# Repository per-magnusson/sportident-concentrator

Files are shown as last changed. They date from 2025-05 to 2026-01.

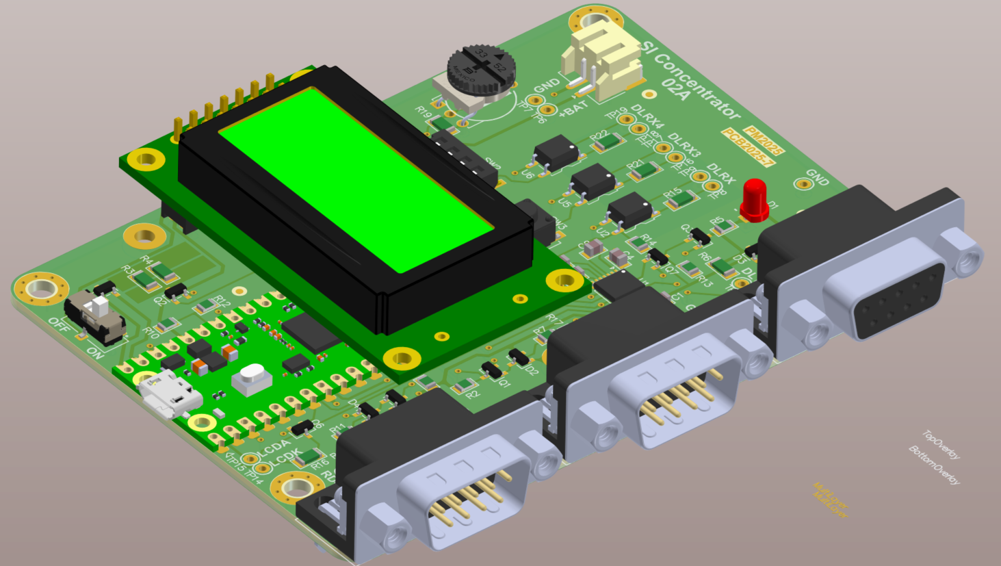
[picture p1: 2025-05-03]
hardware/SI concentrator 3D.png

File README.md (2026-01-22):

# Sportident Concentrator Box

This project consists of both the hardware and the software for a Sporitdent  
concentrator box based on a Raspberry Pi Pico.

photo of the concentrator

It is useful in the sport of orienteering where the Sporitdent punching system is used and allows
punch data from the terrain to be brought in real time to the speaker at the event and to online results. The box
can receive punch data from up to four BSF7 RS232 statations (or other concentrator boxes), plus from a 
long wire from another concentrator box. It buffers the punch data and sends it out over:

- A long wire (1 km or even more is supported)  
- A USB port to a computer  
- An RS232 serial port  

It can be powered by a USB power bank, from a computer via the USB cable or from a pack of e.g. three AA
batteries or another source that provides between 1.8 and 5.5 V.

The box supports both the old Sportident legacy protocal and the current 
extended protocol. It adapts to the speed on the serial port which can be either
4800 or 38400 baud.

It is possible to build a version (useful e.g. at the event center) on the same PCB which has up to three opto-isolated 
long-wire inputs (and correcpondingly fewer RS232 inputs) to receive data from three different long wires.

Since the box in its normal configuration has a long-wire input, it is possible to daisy-chain a number of
concentrator boxes from e.g. the pre-warning via the last control.

To significantly simplify verification of the setup and troubleshooting in the field, there is a 2x8 character 
display that constinuously shows the status of the various inputs. Right after a packet of punch data is 
received, the display shows the card number and station code. 

The USB port shows up as a serial adapter and the punch data can be received by MeOS, OLA and
other orienteering administration software.

The design is based on a Raspeberry Pi Pico (both the original and Pi Pico 2 works) and the code
can be compiled in the Arduino environment.

The project contains the source code, files for manufacturing and assembling the PCB and
files for 3D-printing the enclosure.

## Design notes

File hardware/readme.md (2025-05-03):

# Layout

The board looks something like this:

PCB Rendering

The board has two layers, where most of the routing and the components are on the top side. The 
bottom side is mostly ground plane. Here are the layers:

Top layout
Bottom layout

Here is the assembly drawing:

Assembly drawing

Vectorized versions are avaialble as PDFs in the repo.

Gerber and assembly files are available in the zip files in the repo. The PCB file is the gerbers for the PCB. 
The PCA file contains what is needed for assembly.

The bill of materials (BOM) should be self-explanatory.

# Schematic overview

The schematic is available as a single-page PDF in the repo.

Assembly drawing

## Notation

Components marked "NM" are normally Not Mounted,

## Processor

At the core of the deisgn is a Raspberry Pi Pico 2 board (Pi Pico also works if the code is compiled for that). It 
contains the processor, a USB port and a buck/boost voltage converter. Using this inexpensive board simplifies the rest
of the design so that it should be rather easy to hand-solder for most people with at least a little soldering
experience.

## Power

Power normally comes via the USB cable, either from a power bank or from a computer. There are also provisions to power 
the board from a battery pack (via P5) with a voltage between 1.8 and 5.5 V. E.g. using three AA batteries. The power 
switch SW1 only has an effect if using the battery pack option. Power via the USB port always turns the board on.

Q4 disconnects the battery if power is available from the USB port.

## Serial ports

There are three DB9 connectors directly on the board: two male inputs to be connected to Sportident BSF7 RS232 statations and
one female output to be connected to a serial port on a computer or to another concentrator box. Two more input ports
can easily be added to TP10/TP11 and TP12/TP13, but the DSUB connectors need to be connected to these points by wire.
Alternatively, one or both of these inputs can be configured for long-wire reception by mounting U5/R21 and/or U6/R22 
instead of Q1 and/or Q5.

Only one "proper" RS232 line driver/receiver is used (U1) as there is only one RS232 output. The inputs can be handled
in a simpler and cheaper way by discrete solutions using a MOSFET and a handful of resistors (and ESD protection diodes).

The optocoupler U2 (connected to TP8/TP9) allows for an additional long-wire input from another concentrator box. 

There is also a long-wire output, built around Q7/Q3. It transmits the same data as that transmitted on the serial port
outputs. It is best to use 4800 baud on the long wires as that ensures that reflections are not a problem. Maybe 38400
might work, but that has not been tested and the data volumes in any reasonable scenario are so low that 4800 will do 
just fine. An LED, D1, flashes along with the data sent on the long wire output, which might be helpful during debugging,
particularly if the LCD is not fitted. With the LCD in the design, the LED could be left out without any real loss in 
debuggability.

At least 1 km of DL 1000 cable can be used as the long wire.

If the USB cable is connected to a computer, it shows up as a serial port and the punch data can be received 
by most orienteering administrative software, like OLA and MeOS without any need for a separate RS232-to-USB adapter.

## LCD

The 2x8 character LCD U4 allows for monitoring the status of the box and the communication. This greatly simplifies 
troubleshooting and verification of the setup in the field. However, if it is very important to keep the cost down,
the LCD can be left out without having to modify the software.

The LCD contrast can be adjusted by R18, or if the ideal value is known, the fixed R19 can be mounted instead.

The backlight of the LCD can be controlled by Q6.

The LCD can be mounted on 3D-printed spacers and connects to the main board via a 2x7 pin header.

## Power bank keep-alive

A common way of powering the concentrator box is from a USB power bank via the USB cable. The power consumption 
is however so low that most power banks think that no load is connected, so the power bank switches off its 
output after 30 seconds or so. To prevent this, Q2/R3/R4 can be used to periodically pull more current from
the source to prevent the power bank from going to sleep.

## Config switches

There are provisions for mounting a four-pole DIP switch (SW2) and a push button (SW3). These could be used for 
configuring the device in various ways, but the current software does not read these switches. Accessing
them would requre disassembling the box, which is a bit inconvenient in the field as it requires unscrewing four 
screws. It is probably best to leave these switches unpopulated.
best to not fit them. Configuration could of course also be done by changing and recompiling the code.

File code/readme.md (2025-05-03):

## Compiling

This code is meant to be compiled in the Arduino environment with the addition of the 
Raspberry Pi Pico RP2040/RP2350 board package by Earle F. Philhower, III.
It works on both the Pi Pico and Pi Pico 2 boards.

## The Sportident autosend protocol

The code in SerialInput.cpp handles both the legacy and extended Sportident protocols 
for autosend data. Other kinds of Sportident packages are forwarded as well, but that 
is not thought to be a valid use case, nor is it tested much.

Each packet contains a 16-bit CRC. This is not checked. Packets are passed on regardless 
if the CRC is valid or not.

## Serial ports

PIO/Software serial ports are used throughout. Documentation for the serial port library 
can be found at [Readthedocs](https://arduino-pico.readthedocs.io/en/latest/piouart.html)

Input is taken from up to five serial ports. A standard way of building the box is to have 
four DB9M inputs and one (opto-isolated) long-wire input, but one can e.g. build it with just 
three long-wire inputs. In the latter case, it is suggested that the line:

    #define RECEIVE_ONLY 0

In SI-concentrator.ino is changed to:

    #define RECEIVE_ONLY 1

This changes the printouts on the LCD to only show status of the three ports and defaults them 
all to 4800 baud, which is the speed used on the long wire.

Initially, if an invalid packet is received, the serial speed is toggled between 
4800 baud and 38400 baud. Once a valid packet has been received, the speed is locked 
for that input. Except for the long wire input, the starting speed is 38400.

The output is sent to three places:

1. The female DB9 connector
2. The long-wire output (supports at least 1 km of DL-1000 wire)
3. The USB serial port

## Link status

The (optional) 2x8 LCD displays the status of the different inputs as well as the battery
voltage. There is one character position for each of the five inputs. The possible status 
characters and their meanings are:

'?' - Nothing has been received  
'f' - An invalid packet was received  
't' - There was a timeout while recieving a packet  
'u' - A valid packet of an unexpected type was received  
'tick' - A perfectly valid extended protocol autosend packet was recevied  
'L/E' - A perfectly valid legacy protocol autosend packet was recevied

The status display toggles between the above characeters and another character showing the
link speed for each input:

'3' - 38400 baud  
'4' - 4800 baud

As soon as a valid packet has been received, the backlight is turned on and the card number
as well as the station code is shown for a few seconds. This greatly helps in verifying the
operation of the setup.

## Powerbank keep-alive

A common way of powering the concentrator box is from a USB power bank via the USB cable.
The power consumption is however so low that most power banks think that no load is 
connected, so the power bank switches off its output after 30 seconds or so. To prevent
this, there is a software-controlled feature to periodically (every 25 seconds) draw 
extra current for 1.1 seconds. This prevents the power bank from going to sleep and 
powering down the concentrator box.

It might be necessary to tweak the timing of the current pulses to fit with some specific 
USB power bank. This is done by the following lines in the .ino file:

    static const uint32_t POWER_BANK_PULSE_MS = 1100;         // Length of power bank keep-alive pulse
    static const uint32_t POWER_BANK_PULSE_PERIOD_MS = 25000; // Time between power bank keep-alive pulses

## Debugging

To enable debug printouts, a line in the file debug.h should be changed from:

    #define DEBUG 0
  
to

    #define DEBUG 1
  
This sends debug printouts to the USB serial port. This obviously breaks the Sporitdent 
protocol on that port.

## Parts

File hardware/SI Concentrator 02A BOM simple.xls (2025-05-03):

Product: |  | SI Concentrator
BOM date: |  | 2025-05-03 16:38
Author: |  | PM
# of parts in BOM: |  | 47
# of different parts: |  | 17
Designators | Qty | Description | Package | Manufacturer | Manufacturer PN | Supplier | Supplier PN | Supplier 2 | Supplier 2 PN
R5 | 1 | Resistor, 330 ohm, 0805, 1%, 0.125W | 0805 |  |  | Digikey | 311-330CRCT-ND
R2, R7, R9, R11, R13, R14, R17, R20 | 8 | Resistor, 3.3 kohm, 0805, 1%, 0.125W | 0805
R8, R10, R12 | 3 | Resistor, 47 kohm, 0805, 1%, 0.125W | 0805
R1, R3, R4, R6, R15, R16, R21, R22 | 8 | Resistor, 100 ohm, 1206, 1%, 0.25W | 1206
R18 | 1 | Thumb trimmer, 1 k, 20%, 0.5W, cermet, 250 degrees | PTH | Bourns | 3352E-1-102LF | Digikey | 3352E-102LF-ND | Mouser | 652-3352E-1-102LF
C1, C2, C3, C4, C5 | 5 | Capacitor, 1 uF, 10%, 0805, X7R, 16V | 0805 |  |  | Farnell | 9227792 | Digikey | 1276-6471-1-ND
D2, D3, D4 | 3 | BAV99, dual diode, common anode/cathode, 0.1A, 75V | SOT23 | Taiwan Semiconductor | BAV99,215 | Elfa | 70-181-61 | Digikey | 1727-2914-1-ND
Q1, Q2, Q3, Q5, Q6, Q7 | 6 | BSS138K, NMOS, 50V, 0.2A, 2 ohms, Vth=0.6-1.2V | SOT23 | Fairchild | BSS138K | Digikey | BSS138KCT-ND
 | 0 | DMG2305, PMOS, 0.9V Vth, 20V, 4.2A, 52 mohm | SOT23 | Diodes Inc | DMG2305UX-13 | Digikey | DMG2305UX-13DICT-ND | Mouser | 621-DMG2305UXQ-7
D1 | 1 | 3mm red LED, 35 mcd, 20 mA, 60 degrees, 2.2 V | 3mm | Würth | 151031SS06000 | Mouser | 710-151031SS06000
U1 | 1 | MAX3232, dual RS232 transceiver, 3-5.5 V, 250 kbit/s | TSSOP16 | Texas Instruments | MAX3232EIPWR | Digikey | 296-19436-1-ND | Mouser | 595-MAX3232EIPWR
U3 | 1 | Raspberry Pi Pico 2, SMD version | SMDDIP40 | Raspberry Pi | SC1631 | Mouser | 358-SC1631 | Digikey | 2648-SC1631CT-ND
U2, U5, U6 | 3 | TLP182, optocoupler, AC/DC | 4-SOP | Toshiba | TLP182(GB-TPL,E | Digikey | TLP182(GB-TPLECT-ND | Mouser | 757-TLP182(GB-TPLE
U4 | 1 | 8x2 alphanumeric transreflective LCD | PTH | Raystar Optronics | RC0802A-TIY-ESV | TME | RC0802A-TIY-ESV
 | 0 | JST PH 2-pin header, right angle | SMD | JST sales | S2B-PH-SM4-TB | Digikey | 455-S2B-PH-SM4-TBCT-ND | Electrokit | 41015809
U1A | 1 | Pin header, 2x7, 2.54 mm spacing | PTH | Adam Tech | PH2-14-UA | Digikey | 2057-PH2-14-UA-ND | Mouser | 737-PH2-14-UA
U1B | 1 | Socket header, 2x7, 2.54 mm spacing | PTH | Würth | 61301421821 | Digikey | 732-61301421821-ND | Mouser | 710-61301421821
J1 | 1 | DSUB9, female, right angle | PTH | Assmann | A-DF 09 A/KG-T2S | Digikey | AE10921-ND
P1, P2 | 2 | DSUB9, male, right angle | PTH | Assmann | A-DS 09 A/KG-T2S | Digikey | AE10968-ND
 | 0 | SPDT slide switch | SMD | Nidec | CL-SB-12B-01T | Digikey | 563-1318-1-ND
 | 0 | Tactile switch, 6x6 mm | SMD | C&K | PTS645SL43SMTR92 LFS | Digikey | CKN10880CT-ND | Mouser | 611-PTS645SL43SMTR92
 | 0 | DIP-switch, 4PST | SMD | Same Sky | DS04-254-2-04BK-SMT | Digikey | 2223-DS04-254-2-04BK-SMT-ND

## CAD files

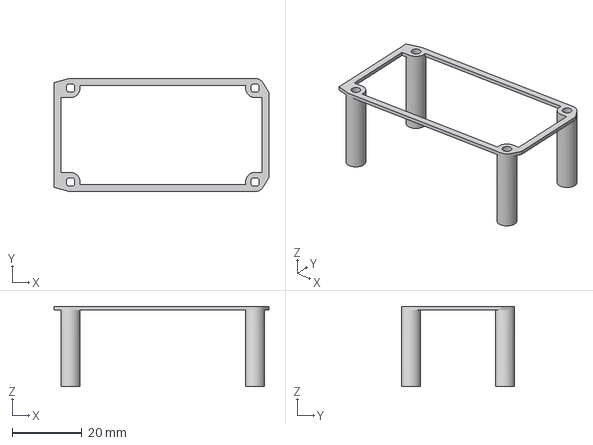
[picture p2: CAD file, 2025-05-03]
3D-printing/LCD standoff.3mf
61.8 x 32.5 x 23.0 mm

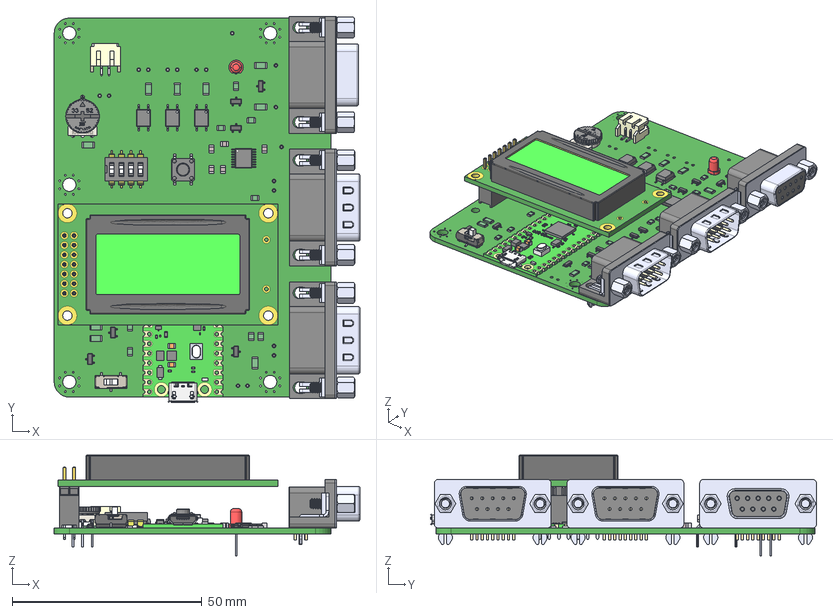
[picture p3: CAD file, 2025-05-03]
hardware/SI Concentrator.step
80.7 x 101.8 x 26.6 mm
TLP182_GB-TPL_E x 3
Extruded x 114
3352E2
sot23-1 x 10
TACT SMD 6X6
Same_Sky_DS04-254-2-04BK-SMT
TSSOP16
_12B-01_c
_2Top setting_s
S2B-PH-SM4-TB
A-DS 09 A_KG-T2S_A-DF 09 A_KG-T2S x 2
A-DF 09 A_KG-T2S_A-DF 09 A_KG-T2S
everlight-3MM-LED-RED
6130xx21821_PIN x 14
lcd
CONN_PH2-14-UA_ADM
ME7SI Concentrator
ME6SI Concentrator
ME5SI Concentrator
PCB, Raspberry Pi Pico-R3
MicroUSB Port, Raspberry Pi Pico-R3
RP2040 Microcontroller, Raspberry Pi Pico-R3
SW1, Tact Switch, Raspberry Pi Pico-R3
D1, Diode, Schottky, Raspberry Pi Pico-R3
D2, QSME-C194, LED, Raspberry Pi Pico-R3
L1, Inductor, Raspberry Pi Pico-R3
U2, RT6150B-33GQW, Buck Boost Converter, Raspberry Pi Pico-R3
U3, W25Q16JVUXIQ, Serial NOR Flash 16 Mbit, Raspberry Pi Pico-R3
Q1, MOSFET, DMG1012T, Raspberry Pi Pico-R3
X1, X12M000000S096, 12 Mhz Crystal Resonator, Raspberry Pi Pico-R3
SMD Resistor, Configurable, Raspberry Pi Pico-R3_R1
SMD Resistor, Configurable, Raspberry Pi Pico-R3_R2
SMD Resistor, Configurable, Raspberry Pi Pico-R3_R3
SMD Resistor, Configurable, Raspberry Pi Pico-R3_R4
SMD Resistor, Configurable, Raspberry Pi Pico-R3_R5
SMD Resistor, Configurable, Raspberry Pi Pico-R3_R6
SMD Resistor, Configurable, Raspberry Pi Pico-R3_R7
SMD Resistor, Configurable, Raspberry Pi Pico-R3_R8
SMD Resistor, Configurable, Raspberry Pi Pico-R3_R9
SMD Resistor, Configurable, Raspberry Pi Pico-R3_R10
SMD Resistor, Configurable, Raspberry Pi Pico-R3_R11
SMD Resistor, Configurable, Raspberry Pi Pico-R3_R12
SMD Resistor, Configurable, Raspberry Pi Pico-R3_R13
SMD Resistor, Configurable, Raspberry Pi Pico-R3_R14
SMD Resistor, Configurable, Raspberry Pi Pico-R3_R15
SMD Capacitor, Configurable, Raspberry Pi Pico-R3_C1
SMD Capacitor, Configurable, Raspberry Pi Pico-R3_C2
SMD Capacitor, Configurable, Raspberry Pi Pico-R3_C3
SMD Capacitor, Configurable, Raspberry Pi Pico-R3_C4
SMD Capacitor, Configurable, Raspberry Pi Pico-R3_C5
SMD Capacitor, Configurable, Raspberry Pi Pico-R3_C6
SMD Capacitor, Configurable, Raspberry Pi Pico-R3_C7
SMD Capacitor, Configurable, Raspberry Pi Pico-R3_C8
SMD Capacitor, Configurable, Raspberry Pi Pico-R3_C9
SMD Capacitor, Configurable, Raspberry Pi Pico-R3_C10
SMD Capacitor, Configurable, Raspberry Pi Pico-R3_C11
SMD Capacitor, Configurable, Raspberry Pi Pico-R3_C12
SMD Capacitor, Configurable, Raspberry Pi Pico-R3_C13
SMD Capacitor, Configurable, Raspberry Pi Pico-R3_C14
SMD Capacitor, Configurable, Raspberry Pi Pico-R3_C15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

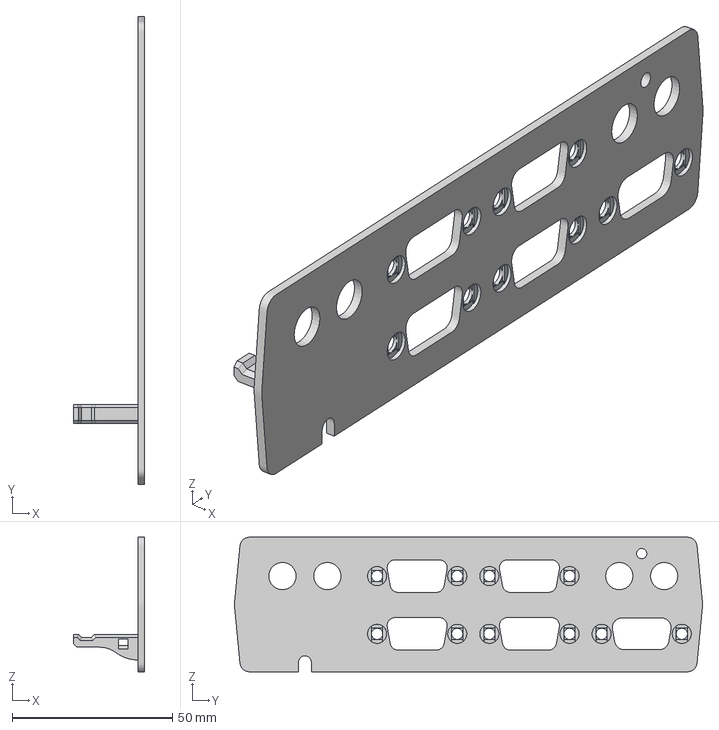
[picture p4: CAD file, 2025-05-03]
3D-printing/SI conc front panel 2.3mf
22.0 x 145.9 x 42.0 mm

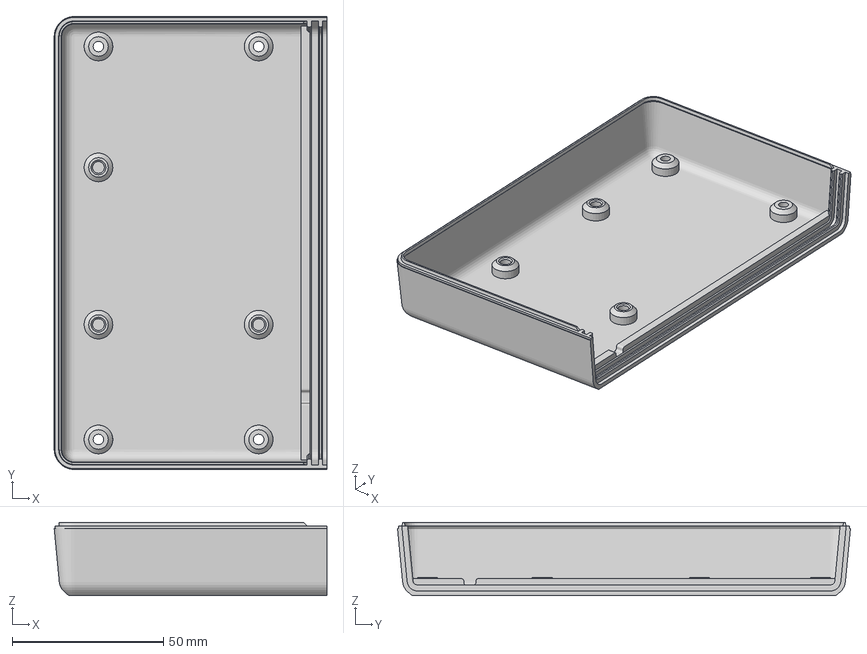
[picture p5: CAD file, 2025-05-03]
3D-printing/SI conc box bottom 2.3mf
90.2 x 149.9 x 24.2 mm

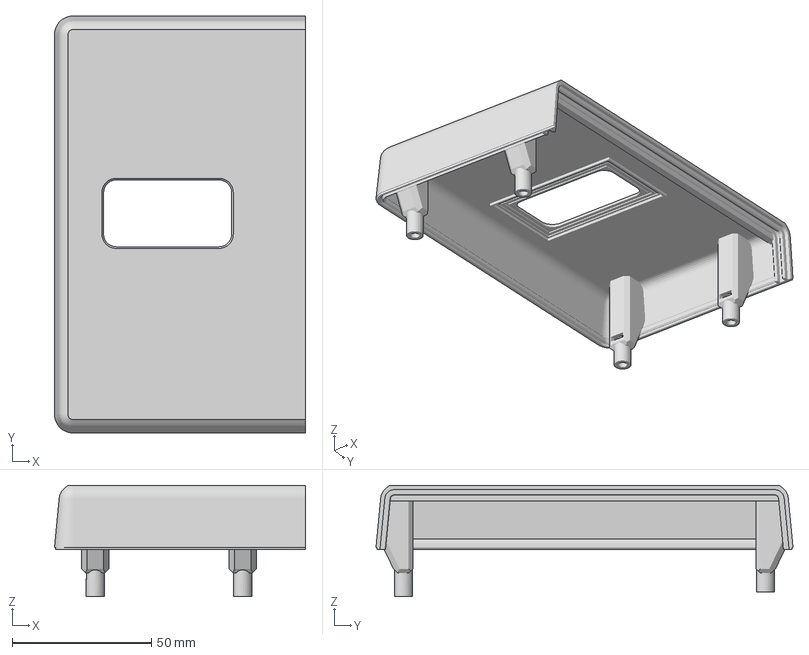
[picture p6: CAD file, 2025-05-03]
3D-printing/SI conc box top 2.3mf
90.2 x 149.9 x 40.0 mm

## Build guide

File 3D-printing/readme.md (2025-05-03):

# Files for 3D printing

The box

The box consists of a bottom, a top and front panel. There is also a four-pillar standoff for the LCD.
All fit on the bed of e.g. a Prusa Mk 3/4 and print without supports.

The box

In addition to the 3D-printed parts, the following additional items are needed:

- A window, 53x31 mm, 1-2 mm thick made of some clear plastic  
- Epoxy glue for the window  
- Three M3 threaded inserts, e.g. IUB-M3-1  
- Three M3 x 6 screws for holding the PCB  
- Four square M3 nuts, e.g. Bossard 1092480  
- Four M3 x 20 screws for holding the box together  
- Eight M2.5 x 6 screws for attaching the LCD  
- A micro USB cable  
- Two small cable ties for strain relief of the USB cable  
- Ten DSUB screwlocks, e.g. Amphenol 863001TLF  
- Four panel-mount banana jacks  
- Wires for connecting the connectors to the board

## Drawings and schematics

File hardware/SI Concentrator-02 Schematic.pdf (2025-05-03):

# SI Concentrator

Date | Revision | Description

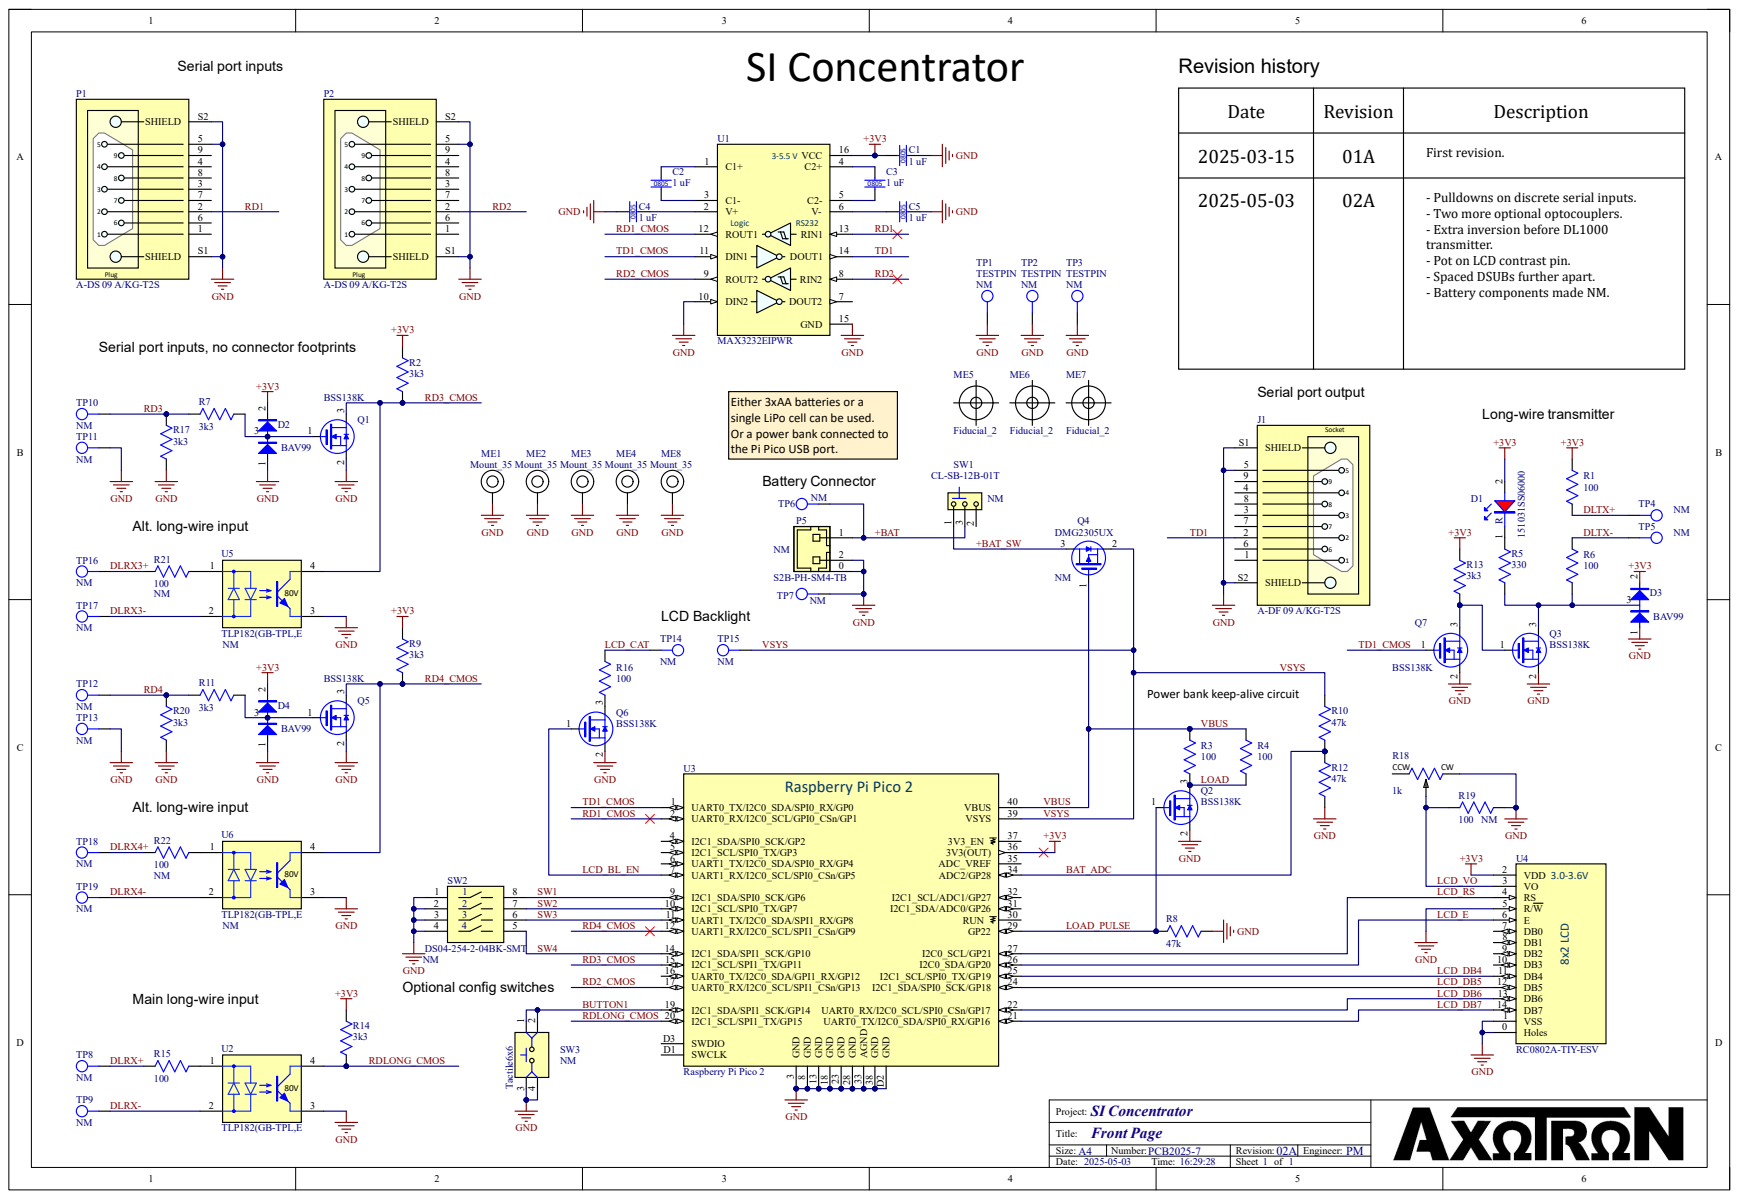
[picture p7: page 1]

- Two more optional optocouplers.
- Extra inversion before DL1000
transmitter.
- Pot on LCD contrast pin.
- Spaced DSUBs further apart.
- Battery components made NM.

Serial port inputs, no connector footprints

Either 3xAA batteries or a
single LiPo cell can be used.
Or a power bank connected to
the Pi Pico USB port.

GND
Alt. long-wire input

Power bank keep-alive circuit

Optional config switches Main long-wire input

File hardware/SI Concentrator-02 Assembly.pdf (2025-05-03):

J1

# D1 R²

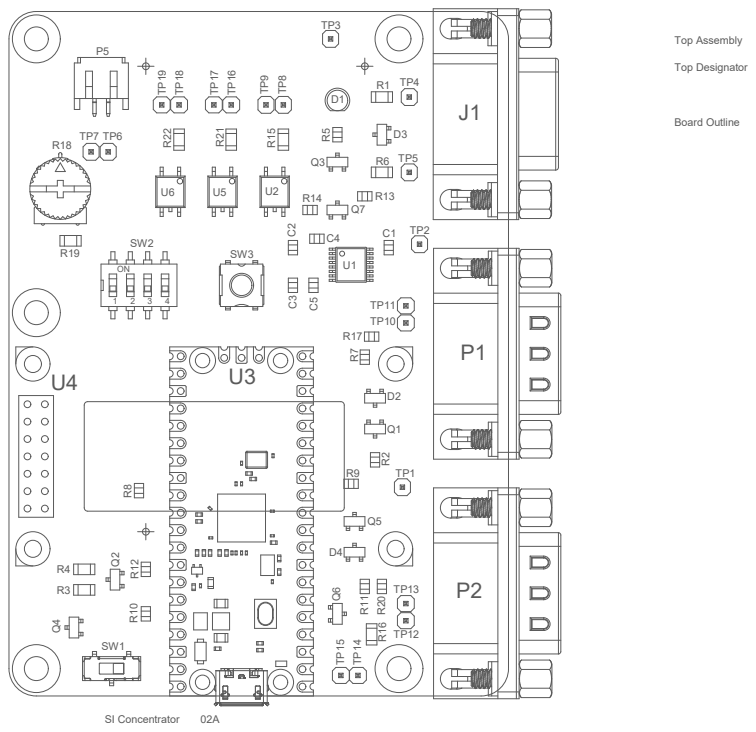
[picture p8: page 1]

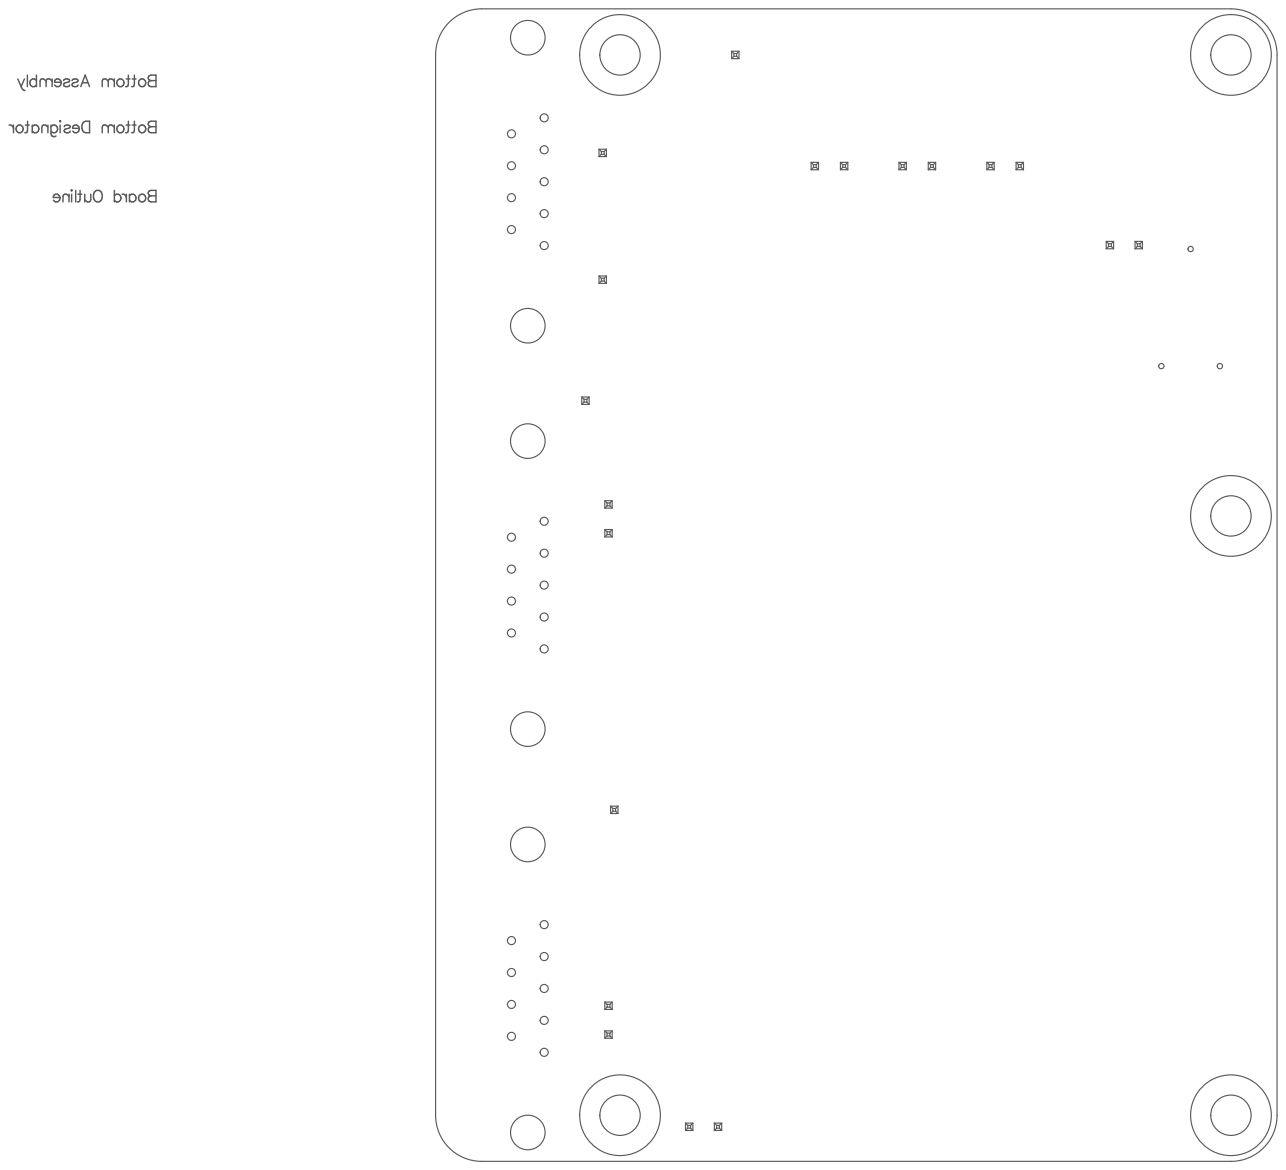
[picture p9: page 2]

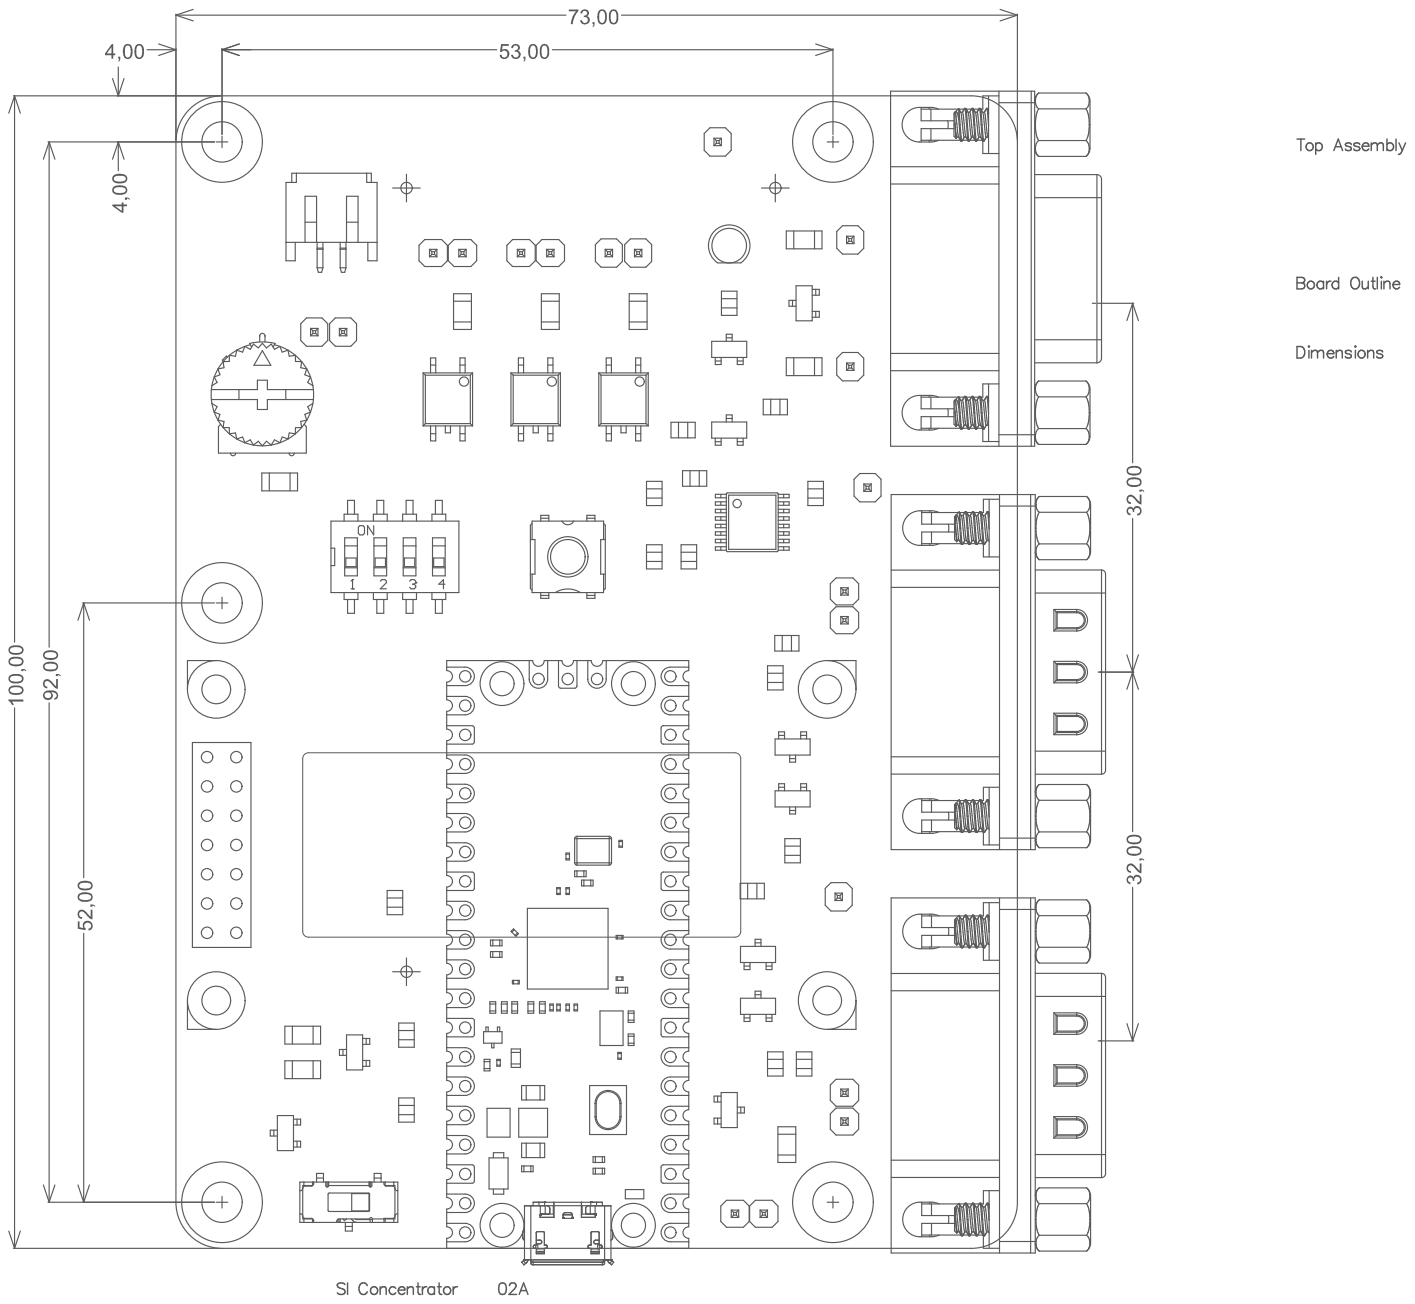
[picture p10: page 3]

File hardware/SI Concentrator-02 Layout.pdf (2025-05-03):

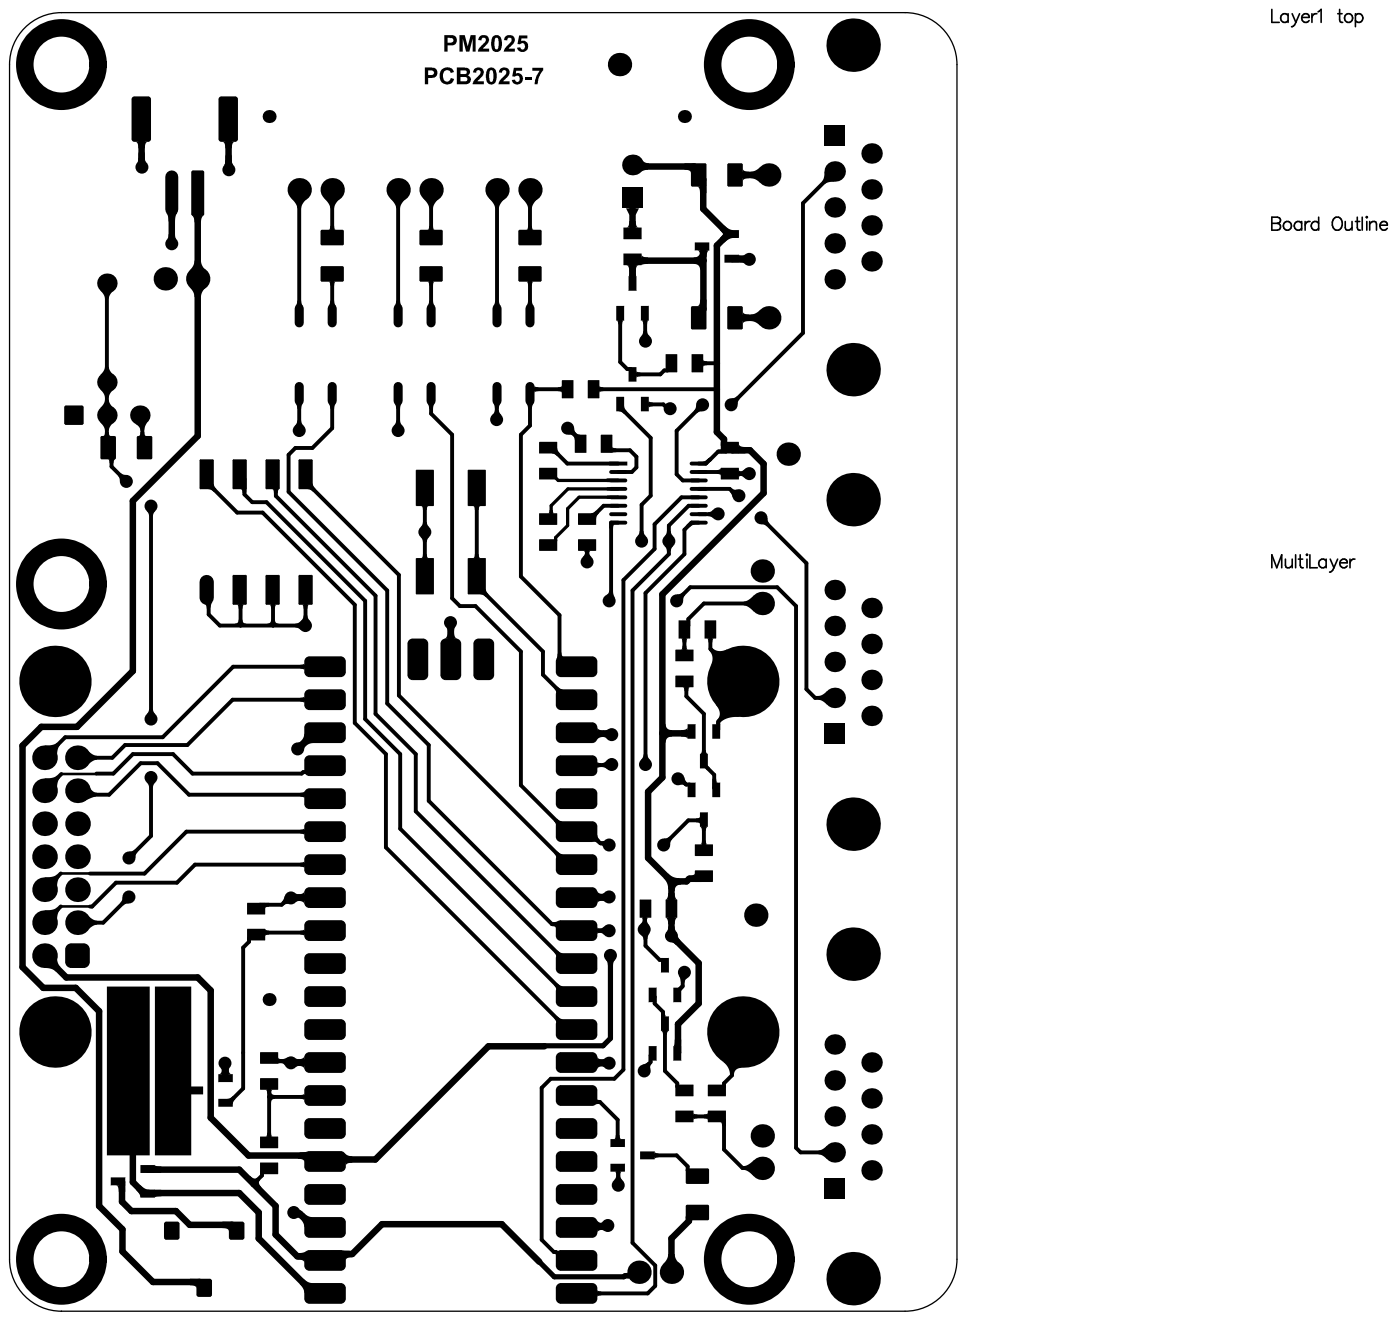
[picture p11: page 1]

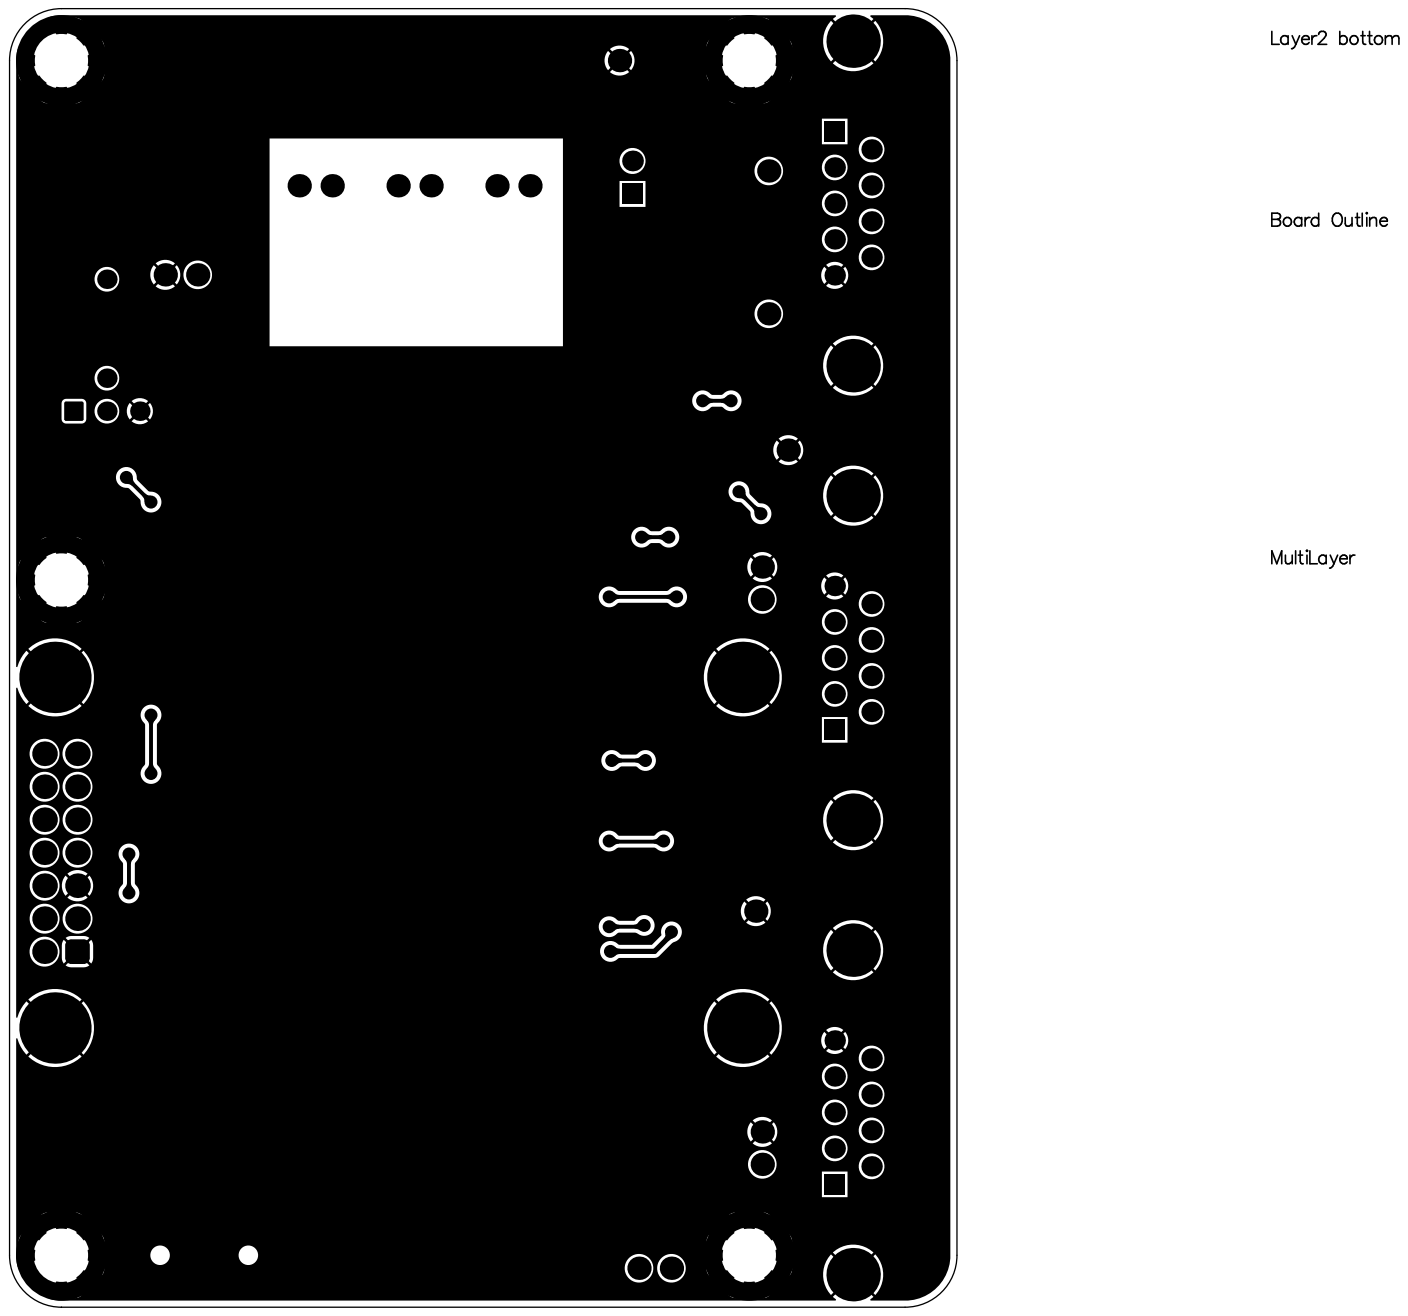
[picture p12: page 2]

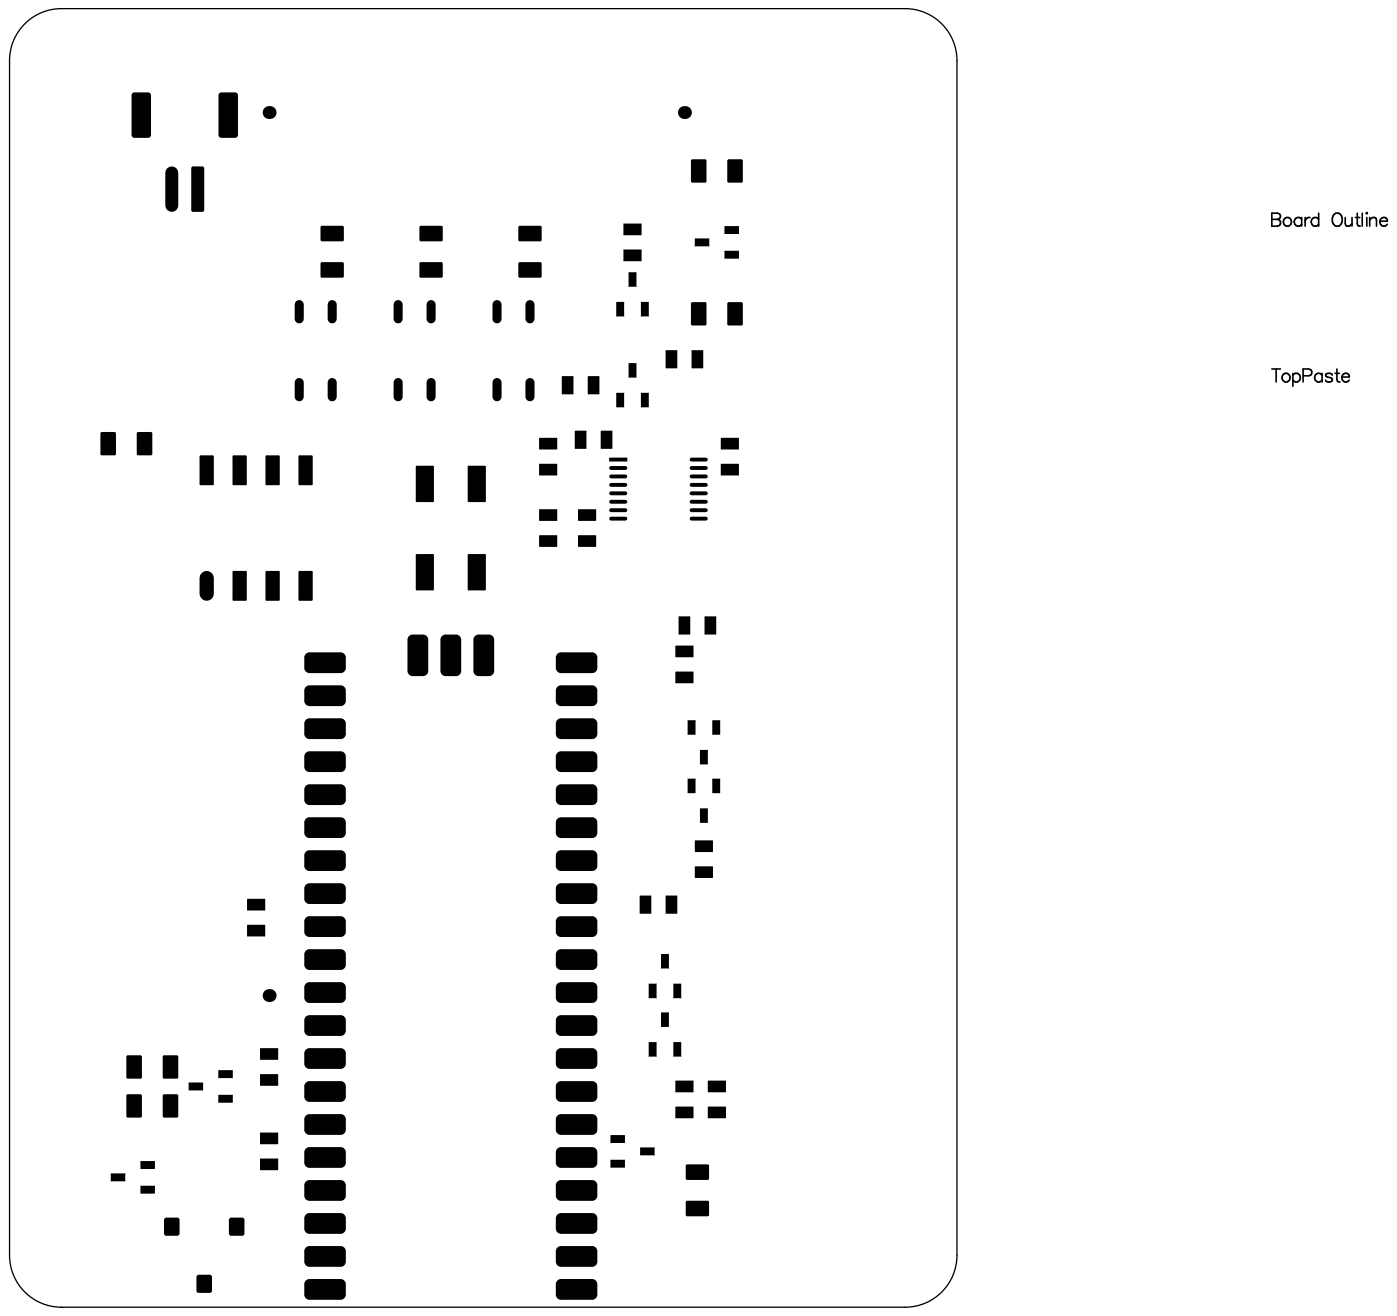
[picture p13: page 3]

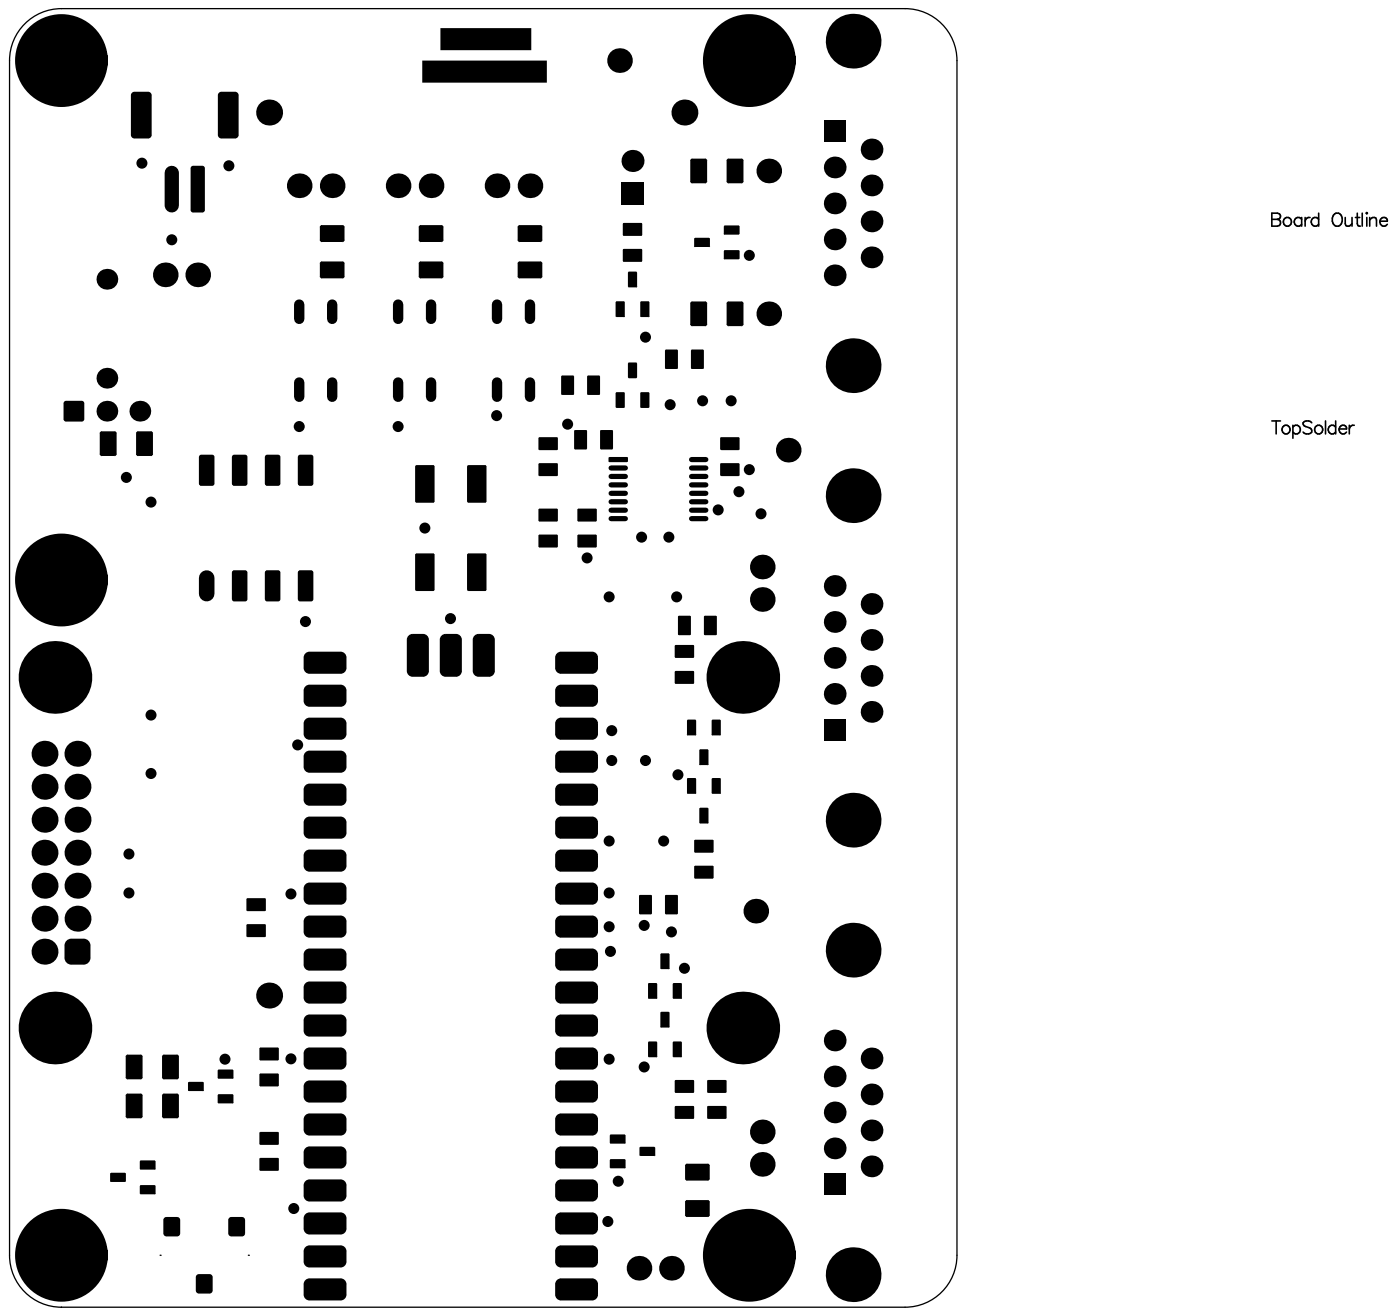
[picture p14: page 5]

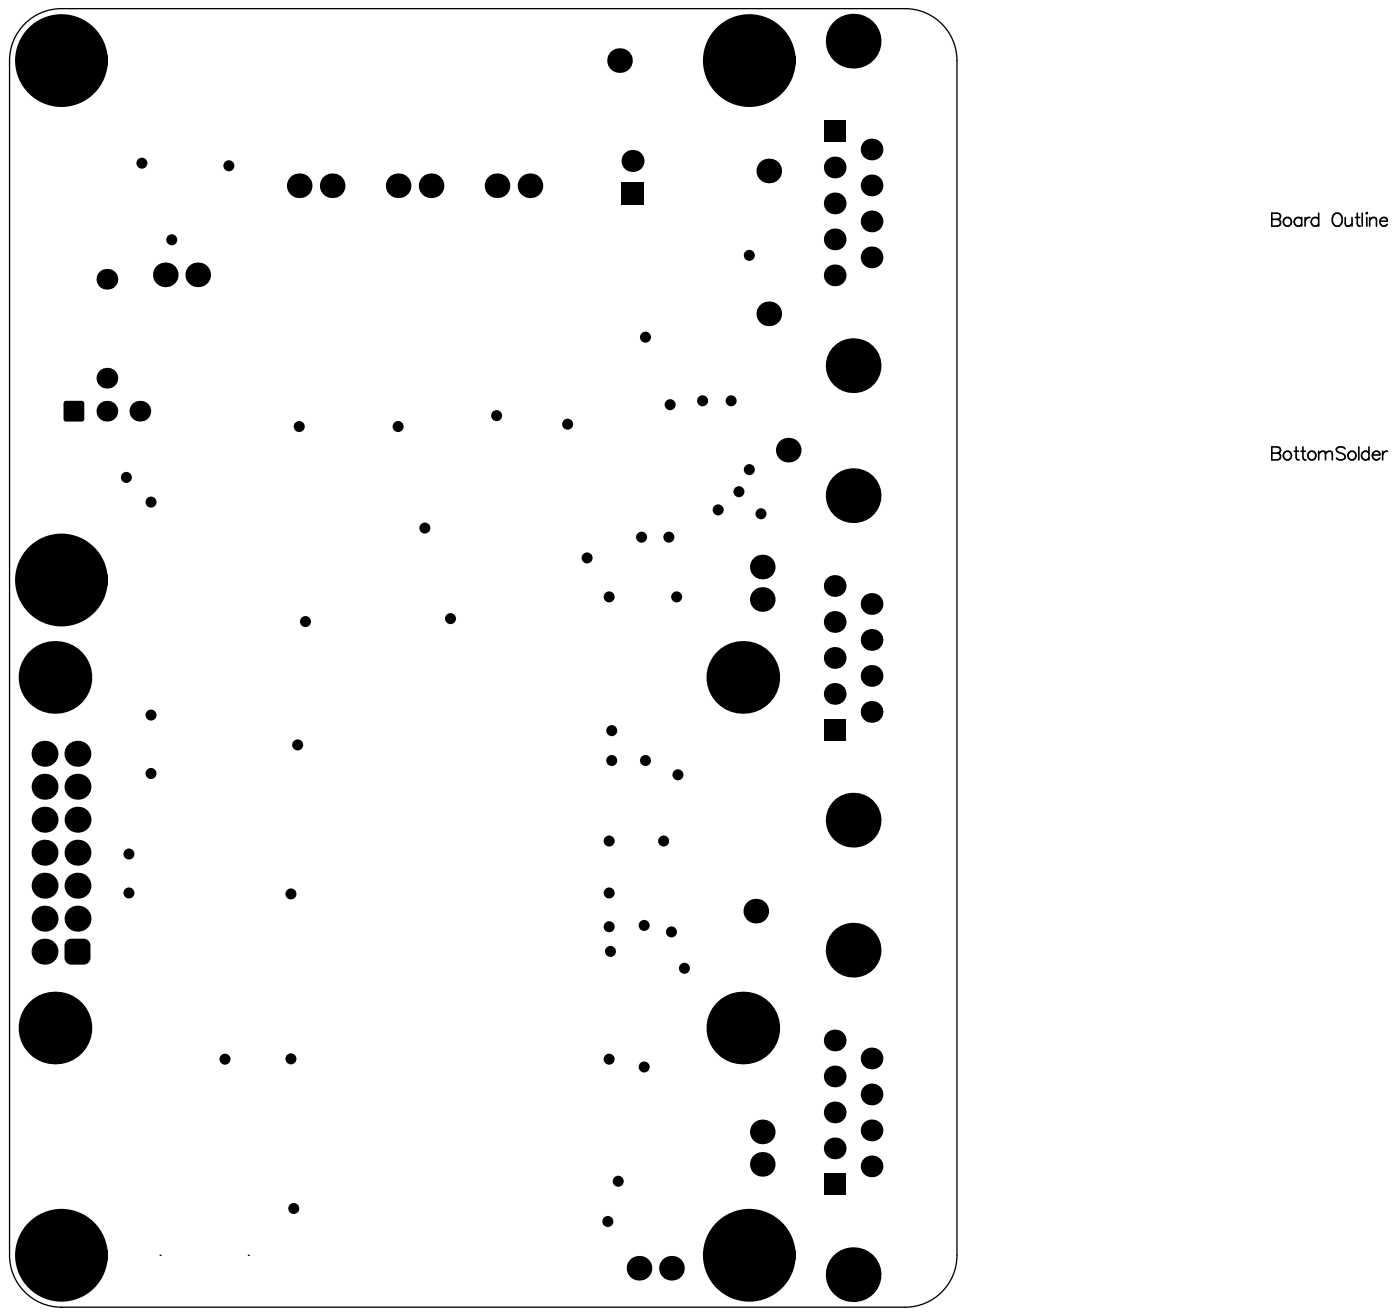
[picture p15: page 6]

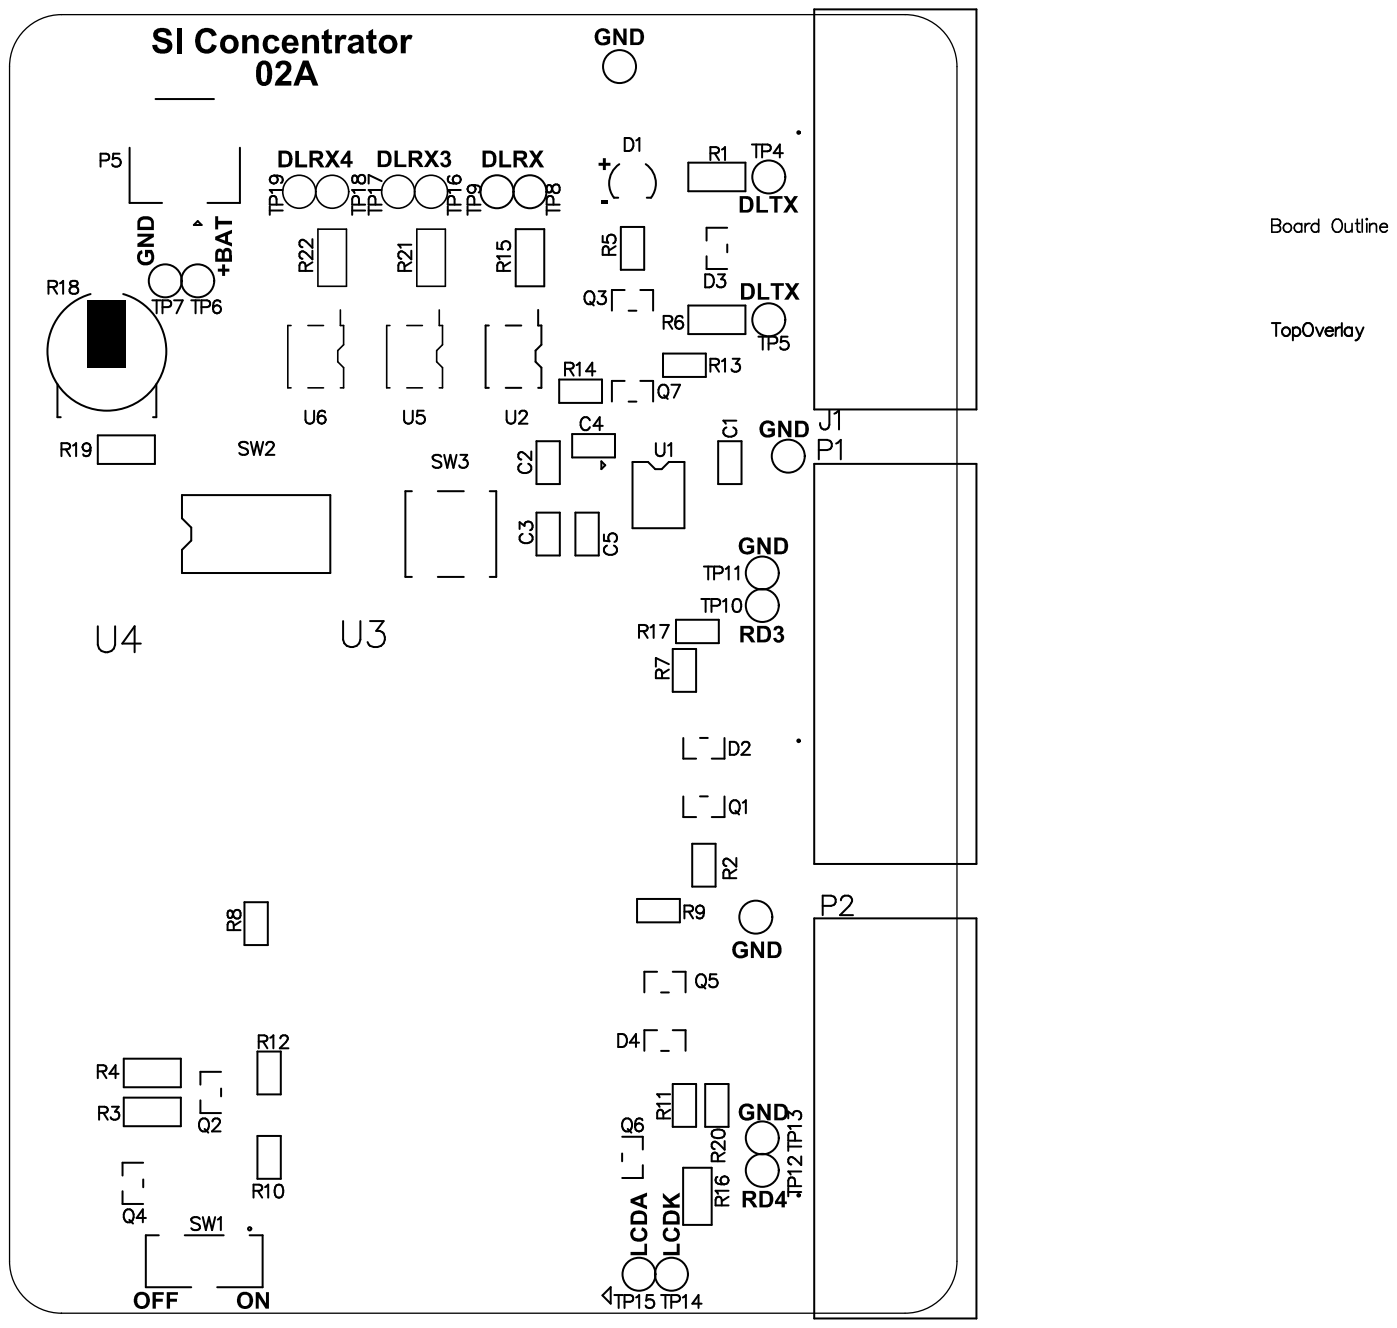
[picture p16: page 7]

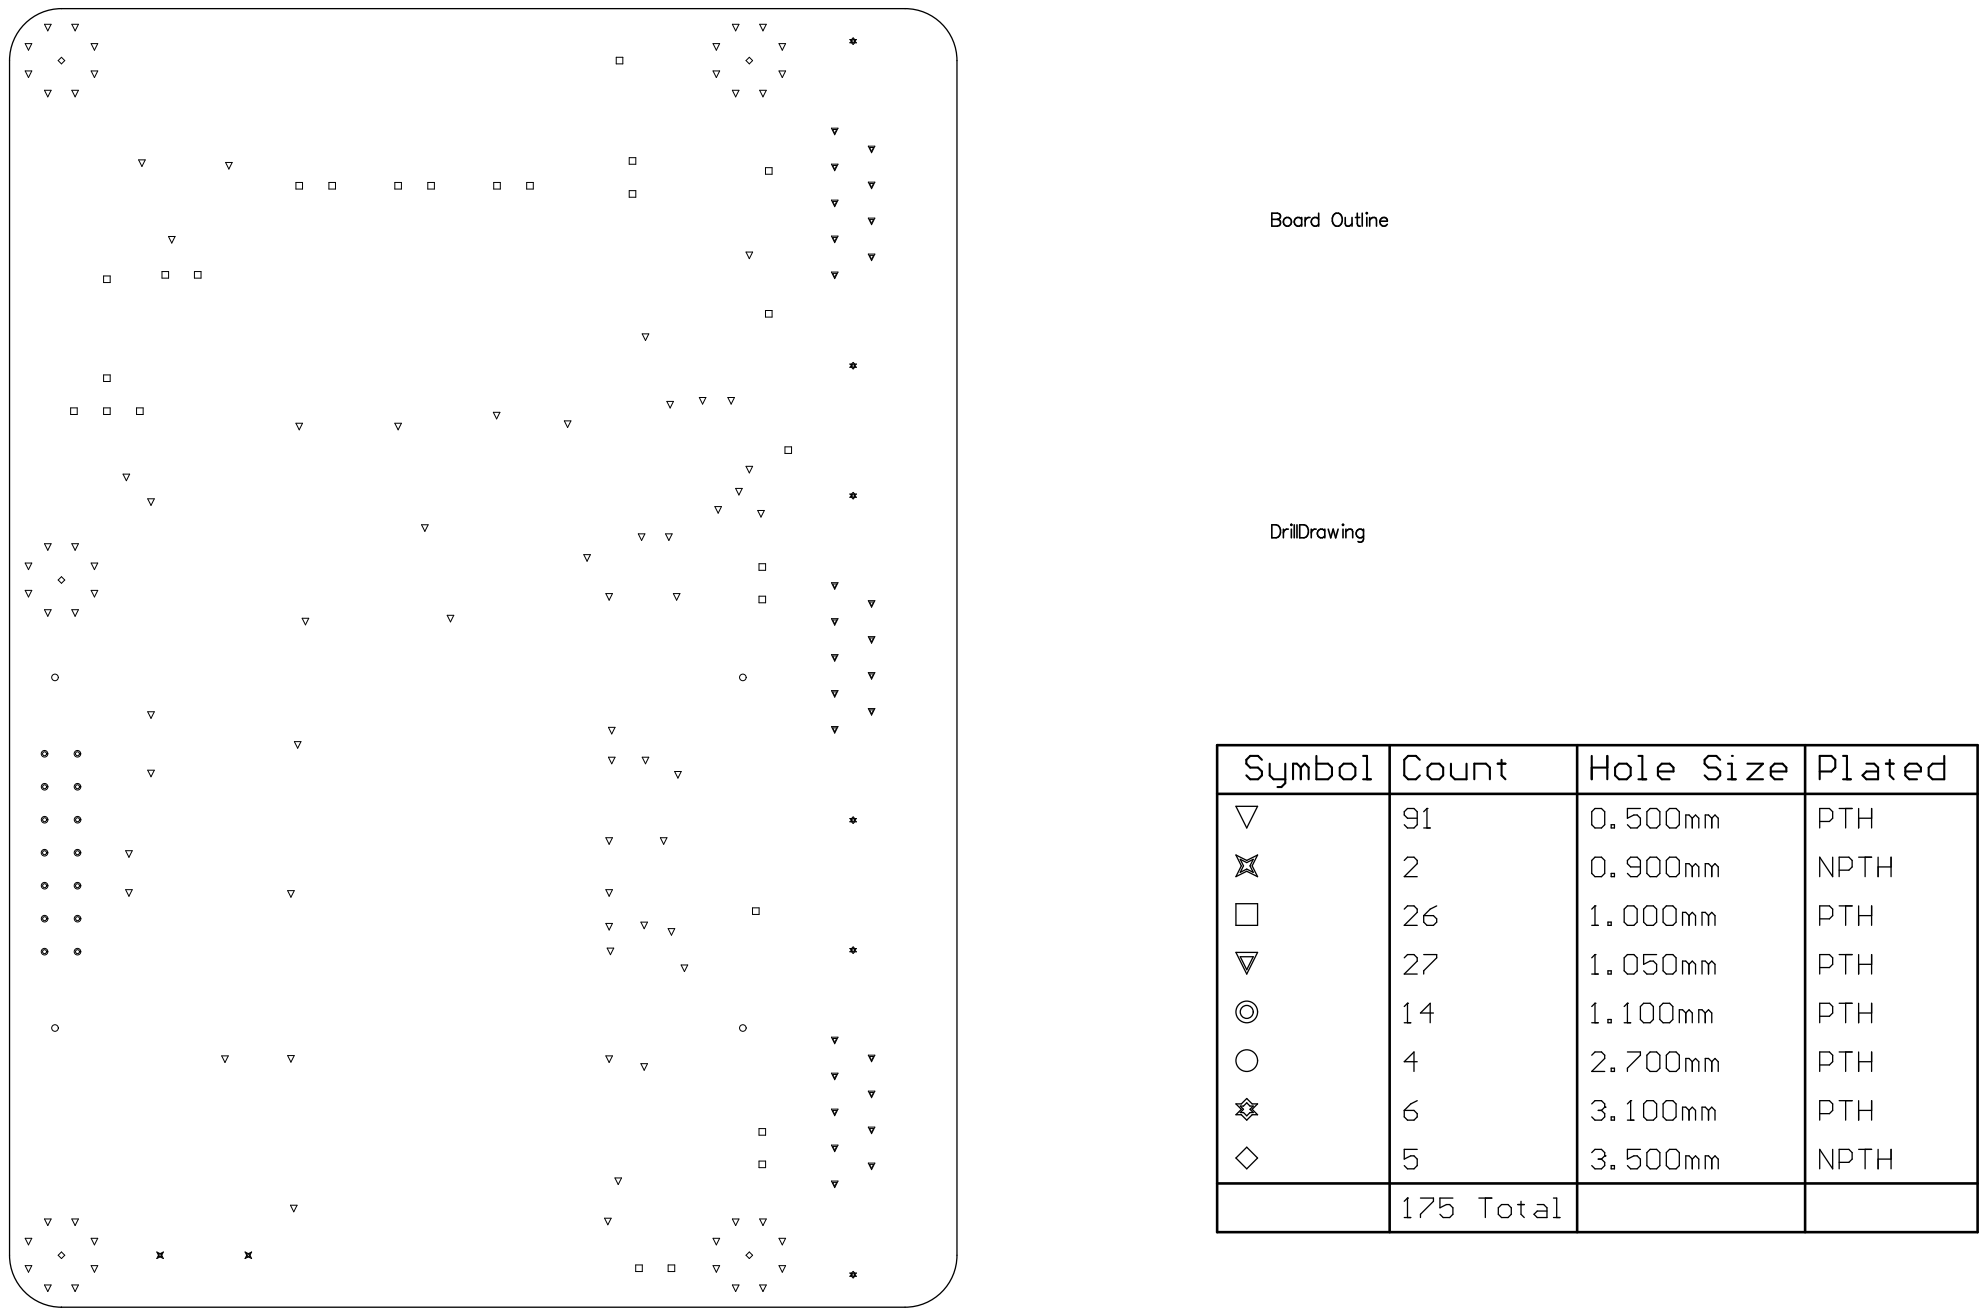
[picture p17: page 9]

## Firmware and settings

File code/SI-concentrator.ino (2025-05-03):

// Concentrator for Sportident stations. Four serial port inputs, 
// one long wire input, one serial port output and one USB output.

// Documentation for PIO UART:
// https://arduino-pico.readthedocs.io/en/latest/piouart.html

#include <LiquidCrystal.h>
#include <elapsedMillis.h>
#include "SerialInput.h"
#include "lcd_util.h"
#include "debug.h"

// Configure the code for use as a triple long-wire receiver rather than the normal concentrator box
#define RECEIVE_ONLY 0

static const uint32_t POWER_BANK_PULSE_MS = 1100;         // Length of power bank keep-alive pulse
static const uint32_t POWER_BANK_PULSE_PERIOD_MS = 25000; // Time between power bank keep-alive pulses


// Use only software serial ports to allow for different baud rates on TD1/RD1 and 
// make all accesses to the ports identical.
// The USB port is used as an additional serial output.
static const int TD1_Pin = 0;
static const int RD1_Pin = 1;
static const int RD2_Pin = 13;
static const int RD3_Pin = 11;
static const int RD4_Pin = 9;
static const int RD5_Pin = 15;

static const int LED_Pin = 25;
static const int LCD_Backlight_Pin = 5;
static const int SW1_Pin = 6;
static const int SW2_Pin = 7;
static const int SW3_Pin = 8;
static const int SW4_Pin = 10;
static const int Button_Pin = 14;
static const int LCD_RS_Pin = 21;
static const int LCD_EN_Pin = 20;
static const int LCD_D4_Pin = 19;
static const int LCD_D5_Pin = 18;
static const int LCD_D6_Pin = 17;
static const int LCD_D7_Pin = 16;
static const int Batt_Pin = 28;
static const int Resistor_Pin = 22; // To periodically pull power from the power bank so that it does not power off

static const int N_INPUTS = 5; // Number of serial port inputs, must remain at 5 even in RECEIVE_ONLY as a lot is hard-coded for that

static const int LOW_BAUD = 5000;      // Low baud rate, nominal is 4800, but slightly higher works better for some reason
static const int LOW_BAUD_TX = 4800;   // Low baud rate for transmission
static const int HIGH_BAUD = 38400;    // High baud rate


// PIO serial ports
SerialPIO serTX(TD1_Pin, SerialPIO::NOPIN);
SerialPIO ser1(SerialPIO::NOPIN, RD1_Pin);
SerialPIO ser2(SerialPIO::NOPIN, RD2_Pin);
SerialPIO ser3(SerialPIO::NOPIN, RD3_Pin);
SerialPIO ser4(SerialPIO::NOPIN, RD4_Pin);
SerialPIO ser5(SerialPIO::NOPIN, RD5_Pin); // Long wire input
SerialPIO *serial_ports[N_INPUTS+1]; // Array of pointers to the serial input ports so that we can index them

// Serial port protocol handlers
SerialInput serial_input[N_INPUTS + 1]; // use index 1 to N_INPUTS for clearer code (wasting 0)


LiquidCrystal lcd(LCD_RS_Pin, LCD_EN_Pin, LCD_D4_Pin, LCD_D5_Pin, LCD_D6_Pin, LCD_D7_Pin);

elapsedMillis global_time;

uint32_t resistor_time;
uint32_t blink_time;

void lcd_show_splash();


void setup() {
  analogReadResolution(12);
  pinMode(LED_Pin, OUTPUT);

  digitalWrite(Resistor_Pin, LOW);
  pinMode(Resistor_Pin, OUTPUT);
  resistor_time = global_time;
  blink_time = global_time;

  pinMode(LCD_Backlight_Pin, OUTPUT);

  Serial.begin();
  Serial.ignoreFlowControl(true); // This may be necessary e.g. when talking to MeOS as it does not seem to assert the virtual DTR

  lcd.begin(8, 2);
  lcd_define_glyphs();
  lcd_show_splash();

  // Reboot life sign
  int ii;
  ii = 0;
  while (ii++ < 5) {
    digitalWrite(LED_Pin, HIGH);
    digitalWrite(LCD_Backlight_Pin, HIGH);
    sleep_ms(50);
    digitalWrite(LED_Pin, LOW);
    digitalWrite(LCD_Backlight_Pin, LOW);
    sleep_ms(50);
  }

  digitalWrite(LCD_Backlight_Pin, HIGH);

  // Initialize the serial ports array
  serial_ports[0] = NULL; // 0 is not used, start with index 1 for clearer code
  serial_ports[1] = &ser1;
  serial_ports[2] = &ser2;
  serial_ports[3] = &ser3;
  serial_ports[4] = &ser4;
  serial_ports[5] = &ser5;
  int speed;
#if RECEIVE_ONLY
  // Start with 4800 in long-wire receive mode
  speed = LOW_BAUD;
#else
  // Start with 38400 on the serial port inputs
  speed = HIGH_BAUD;
#endif
  for(ii = 1; ii <= 4; ii++) {
    serial_input[ii].set_speed(speed);
    serial_ports[ii]->begin(speed);
  }
  speed = LOW_BAUD;
  serial_input[5].set_speed(speed);
  serial_ports[5]->begin(speed); // Long wire
  // Use 4800 for the long wire
  speed = LOW_BAUD_TX;
  serTX.begin(speed);
}


double read_batt()
{
  // Read the battery voltage
  int acc = 0;
  const int niter = 10;
  double volt;

  for(int ii = 0; ii < niter; ii++) {
    // Average a few times
    acc += analogRead(Batt_Pin);
  }
  // ADC max = 4095 at 3.3 V
  // 1:2 voltage divider
  volt = 2* 3.3 * acc / (double) niter / 4095.0;
  return volt;
}



// Show some information on the LCD as soon as possible after power up.
void lcd_show_splash()
{
  char str[16];

  lcd.clear();
  lcd.print("SIC v1.0");
  // Show the battery voltage
  lcd.setCursor(0, 1); // bottom left
  sprintf(str, "  %.2f V", read_batt());
  lcd.print(str);
}


void led_heartbeat()
{
  static int led_state = 0;

  if(global_time > blink_time + 100) {
    if(led_state) {
      digitalWrite(LED_Pin, LOW);
    } else {
      digitalWrite(LED_Pin, HIGH);
    }
    led_state = !led_state;
    blink_time = global_time + 100;
  }
}


void powerbank_keepalive()
{
  static int state = 0;

  if(state == 0) {
    // Drawing extra power from the power bank
    digitalWrite(Resistor_Pin, HIGH);
    digitalWrite(LED_Pin, HIGH);
    if(global_time > resistor_time + POWER_BANK_PULSE_MS) {
      resistor_time = global_time;
      state = 1;
      digitalWrite(Resistor_Pin, LOW);
      digitalWrite(LED_Pin, LOW);
    }
  } else {
    // Between pulses
    digitalWrite(Resistor_Pin, LOW);
    digitalWrite(LED_Pin, LOW);
    if(global_time > resistor_time + POWER_BANK_PULSE_PERIOD_MS) {
      resistor_time = global_time;
      state = 0;
      digitalWrite(Resistor_Pin, HIGH);
      digitalWrite(LED_Pin, HIGH);
    }
  }
}


void switch_baud(int n)
{
  int new_speed;

  if(serial_input[n].get_speed() < 2*LOW_BAUD) {
    new_speed = HIGH_BAUD;
  } else {
    new_speed = LOW_BAUD;
  }

  debug_printf("Trying %d baud on port %d\n", new_speed, n);
  serial_ports[n]->end();
  serial_ports[n]->begin(new_speed, SERIAL_8N1);
  // Consume garbage
  delay(10);
  while(serial_ports[n]->available() > 0) {
    char c;
    c = serial_ports[n]->read();
    c = c; // To avoid warning about variable that is set but not used when DEBUG is 0
    debug_printf("eating '0x%x' ", (int)c);
    delay(10);
  }
  serial_input[n].set_speed(new_speed);
  debug_printf("\n%d in effect\n", new_speed);
  serial_input[n].reset_link_status();
}


void receive_from_inputs()
{
  uint8_t c;

  for(int ii = 1; ii <= N_INPUTS; ii++) {
    if(serial_ports[ii]->available() > 0) {
      c = serial_ports[ii]->read();
      serial_input[ii].new_byte(c);
    } else {
      serial_input[ii].ping();
    }
    if(!serial_input[ii].link_ok_p()) {
      // Got some invalid data
      // Have we ever got something valid at this speed on this port?
      if(!serial_input[ii].get_ever_ok()) {
        // No, try the other speed
        switch_baud(ii);
      }
    }
  }
}


// Transmit data from the packet buffer, if data is available and the serial port is ready.
void transmit()
{
  static uint8_t *buf = NULL;
  static int buflen = 0;
  static int bufidx = 0;

  if(!buf) {
    buf = packet_buffer.get_packet();
    if(buf) {
      buflen = packet_buffer.get_packet_len();
      bufidx = 0;
      if(buflen < 6) {
        // This should not happen
        debug_println("Short packet!");
        packet_buffer.pop_packet(); // Done with this packet
        return;
      }
    } else {
      // No packet available
      return;
    }
  }

  while(serTX.availableForWrite()) {
    serTX.write(buf[bufidx]);
    if(DEBUG) {
      debug_printf("0x%x\n", buf[bufidx]); // Debug on USB output
    } else {
      Serial.write(buf[bufidx]);
    }
    bufidx++;
    if(bufidx >= buflen) {
      // We have emptied this buffer
      packet_buffer.pop_packet(); // Done with this packet
      debug_println("Pop!");
      buf = NULL;
      buflen = 0;
      bufidx = 0;
      break;
    }
  }
}


// Convert a link status to a character to show on the LCD
char link_stat_to_char(ser_link_status_t stat)
{
  switch(stat) {
    case LS_ZERO: return '?';
    case LS_FAILED: return 'f';
    case LS_TIMEOUT: return 't';
    case LS_UNEXPECTED: return 'u';
    case LS_AUTOSEND: return TICK_CHAR;
    case LS_OK: return TICK_CHAR;
    case LS_LEGACY: return LEGACY_CHAR;
    default: return 'q';
  }
}


// Check to see if any input has received a new valid packet, starting with current_port.
// Return the port number of the next input with a new packet.
int check_inputs(int current_port)
{
  int port;

  port = current_port;
  for(int ii=1; ii <= N_INPUTS; ii++) {
    if(port < N_INPUTS) {
      port++;
    } else {
      port = 1;
    }
    if(serial_input[port].check_new_data()) {
      return port;
    }
  }
  return 0;
}


void update_LCD()
{
  static char ser_stat[N_INPUTS+1]; // Status characters for the input ports, 0 is for port 1, end in '\0'
  char ser_speed[N_INPUTS+1]; // Speed characters for the input ports, 0 is for port 1, end in '\0', 3 == 38400, 4 = 4800
  char new_stat;
  static int current_port = 0; // Which input we are currently showing recent data from, 0 means none
  static uint32_t last_LCD_update = global_time;
  static uint32_t backlight_off_time = global_time + 10000;
  static int state = 1; // 0 => recent punch info, 1 => link status screen, 2 => speed screen
  int card, code;
  char str[16];

  current_port = check_inputs(current_port);
  if(current_port > 0) {
    // New data on current_port, show it on the LCD
    card = serial_input[current_port].get_last_card();
    code = serial_input[current_port].get_last_code();
    serial_input[current_port].ack_new_data();
    lcd.setCursor(0, 0);
    sprintf(str, "%d: c=%3d", current_port, code);
    lcd.print(str);
    lcd.setCursor(0, 1);
    sprintf(str, "%8d", card);
    lcd.print(str);
    digitalWrite(LCD_Backlight_Pin, HIGH);
    last_LCD_update = global_time;
    backlight_off_time = global_time + 10000;
    state = 0;
  }

  if(((state == 0 && (global_time > last_LCD_update + 5000))) ||
     ((state > 0) && (global_time > last_LCD_update + 1000))) {
    // We have not updated the LCD for a while, update and show link status or speed
    // Check the status of the different ports
    for(int ii=1; ii <= N_INPUTS; ii++) {
      new_stat = link_stat_to_char(serial_input[ii].get_link_status());
      if(ser_stat[ii-1] != new_stat) {
        digitalWrite(LCD_Backlight_Pin, HIGH);
        backlight_off_time = global_time + 5000;
      }
      ser_stat[ii-1] = new_stat;

      if(serial_input[ii].get_speed() == LOW_BAUD) {
        ser_speed[ii-1] = '4';
      } else {
        ser_speed[ii-1] = '3';
      }
    }
    ser_speed[N_INPUTS] = '\0';
    ser_stat[N_INPUTS] = '\0'; // NUL terminated string
    lcd.setCursor(0, 0);
    if(state <= 1) {
#if RECEIVE_ONLY
      sprintf(str, "%c%c%c     ", ser_stat[0], ser_stat[1], ser_stat[2]);
#else
      sprintf(str, "%c%c%c%c %c  ", ser_stat[0], ser_stat[1], ser_stat[2], ser_stat[3], ser_stat[4]);
#endif
      state = 2;
    } else {
#if RECEIVE_ONLY
      sprintf(str, "%c%c%c     ", ser_speed[0], ser_speed[1], ser_speed[2]);
#else
      sprintf(str, "%c%c%c%c %c  ", ser_speed[0], ser_speed[1], ser_speed[2], ser_speed[3], ser_speed[4]);
#endif
      state = 1;
    }
    lcd.print(str);
    lcd.setCursor(0, 1);
    sprintf(str, "  %.2f V", read_batt());
    lcd.print(str);
    last_LCD_update = global_time;
  }

  if(global_time > backlight_off_time) {
    digitalWrite(LCD_Backlight_Pin, LOW);
  }
}


void loop() 
{
  powerbank_keepalive();
  receive_from_inputs();
  transmit();
  update_LCD();
}

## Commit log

2025-05-03 Add files via upload
    Adding:
    PDFs of schematics, assembly and layout
    A 3D view of the board
    Geber files (PCB package)
    Assembly file (PCA package)
    [SI Concentrator.step]
2025-05-03 Added BOM
    [SI Concentrator 02A BOM simple.xls]
2025-05-03 Added 3mf models
    [LCD standoff.3mf, SI conc box bottom 2.3mf, SI conc box top 2.3mf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]
